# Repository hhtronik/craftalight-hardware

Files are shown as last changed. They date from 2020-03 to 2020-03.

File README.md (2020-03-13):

# Craftalight / Hardware
Schematics, BOM and mechanical drawings for Craftalight.

If you're looking for the firmware, it's over there: [craftalight-firmware in Github](https://github.com/hhtronik/craftalight-firmware/)

Fully assembled Craftalights are available on [hhtronik.com](https://hhtronik.com/product/craftalight-the-oshw-handbag-led-light/)

## What's in here?

You'll find a BOM with comments/notes, a PDF schematic, ECAD design files for DesignSpark and DXF drawings for the mechanical parts of Craftalight.

## Software

You open and edit most files by using free or open-source software.

- ECAD: DesignSpark PCB v9 by RS Online
- Mechanical: FreeCad or Fusion360

## LICENCE 

This part of the Craftalight project is licenced under **CERN Open Hardware Licence Version 2 - Strongly Reciprocal** see [LICENCE](./LICENCE) file

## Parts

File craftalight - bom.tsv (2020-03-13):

Reference | Component | Package | Value | Notes
SW1 | ALPS SKSNLAE010 |  |  | Tactile switch side mid mount (alternatively Panasonic EVPAEDB2A
C1 | MLCC 0805 10uF X7R | 0805 | 10uF 16V
C2 | MLCC 0402 1uF X7R | 0402 | 1uF 6.3V
C3 | MLCC 0402 1uF X7R | 0402 | 1uF 6.3V
C4 | MLCC 0402 100nF X7R | 0402 | 100nF 25V | Optional for alternative LDO with HF bypass
C6 | MLCC 0805 10uF X7R | 0805 | 10uF 16V
C7 | MLCC 0402 100nF X7R | 0402 | 100nF 25V
C8 | MLCC 0402 1uF X7R | 0402 | 1uF 6.3V
C9 | MLCC 0402 100nF X7R | 0402 | 100nF 25V
C11 | MLCC 0402 1uF X7R | 0402 | 1uF 6.3V
C12 | MLCC 0402 100nF X7R | 0402 | 100nF 25V
Q1 | Diodes Inc. DMG1012UW-7 | SOT-323 | 1A 20V N-mos
Q2 | Diodes Inc. DMG1012UW-7 | SOT-323 | 1A 20V N-mos
LED1 | 5630 Warm white (3200K) LED | 5630 | Vf=2.5V Imax=150mA CRI=85 | ex. OSRAM DURISE5. 5730 package fits footprint
LED2 | 5630 Warm white (3200K) LED | 5630 | Vf=2.5V Imax=150mA CRI=85 | ex. OSRAM DURISE5. 5730 package fits footprint
FS1 | Bourns MF-NSMF150 PTC fuse | 1206 | Umax=6V Ihold=1.5A
U1 | Microchip MIC5365-3.0YC5 LDO | SOT-323 | Uout=3.0V Imax=150mA
U2 | ST STM8S003F3U6TR | UFQFPN20 | 8bit STM8 Microcontroller, 16MHz, 8 kB Flash
U3 | Silicon Labs Si7201-B-05-IV Hall effect switch | SOT23-3 |  | Alternatively GoChip Elec Tech GH1248ESW (higher sensitivity and no tamper detection mode)
J1 | Mid-mount micro USB socket |  |  | XKB Enterprise U253-051T-4BH87
R1 | Resistor 18R 1% 0603 | 0603 | 18 Ohms and >= 1/4W dissipation | ex. Panasonic ERJPA3F18R0V
R2 | Resistor 10K 5% 0402 | 0402
R3 | Resistor 18R 1% 0603 | 0603 | 18 Ohms and >= 1/4W dissipation | ex. Panasonic ERJPA3F18R0V
R4 | Resistor 50R 1% 0603 | 0603 |  | ex. Bourns CR0603-FX-49R9ELF
R5 | Resistor 1M 1% 0402 | 0402
R6 | Resistor 1M 1% 0402 | 0402
R7 | Resistor 1M 1% 0402 | 0402
SO1 | Würth WA-SMSI 9774015243R 1.5mm Steel standoff M2
SO2 Würth WA-SMSI 9774015243R 1.5mm Steel standoff M2
MS1 Bossard BN1435 M2x6mm Phillips screw
MS2 Bossard BN1435 M2x6mm Phillips screw
G1 | EPDM gasket |  |  | 2mm EPDM sheet
CO1 | Acrylic glass, satin |  |  | Material: Plexiglas(r) Satinice(r) 3mm

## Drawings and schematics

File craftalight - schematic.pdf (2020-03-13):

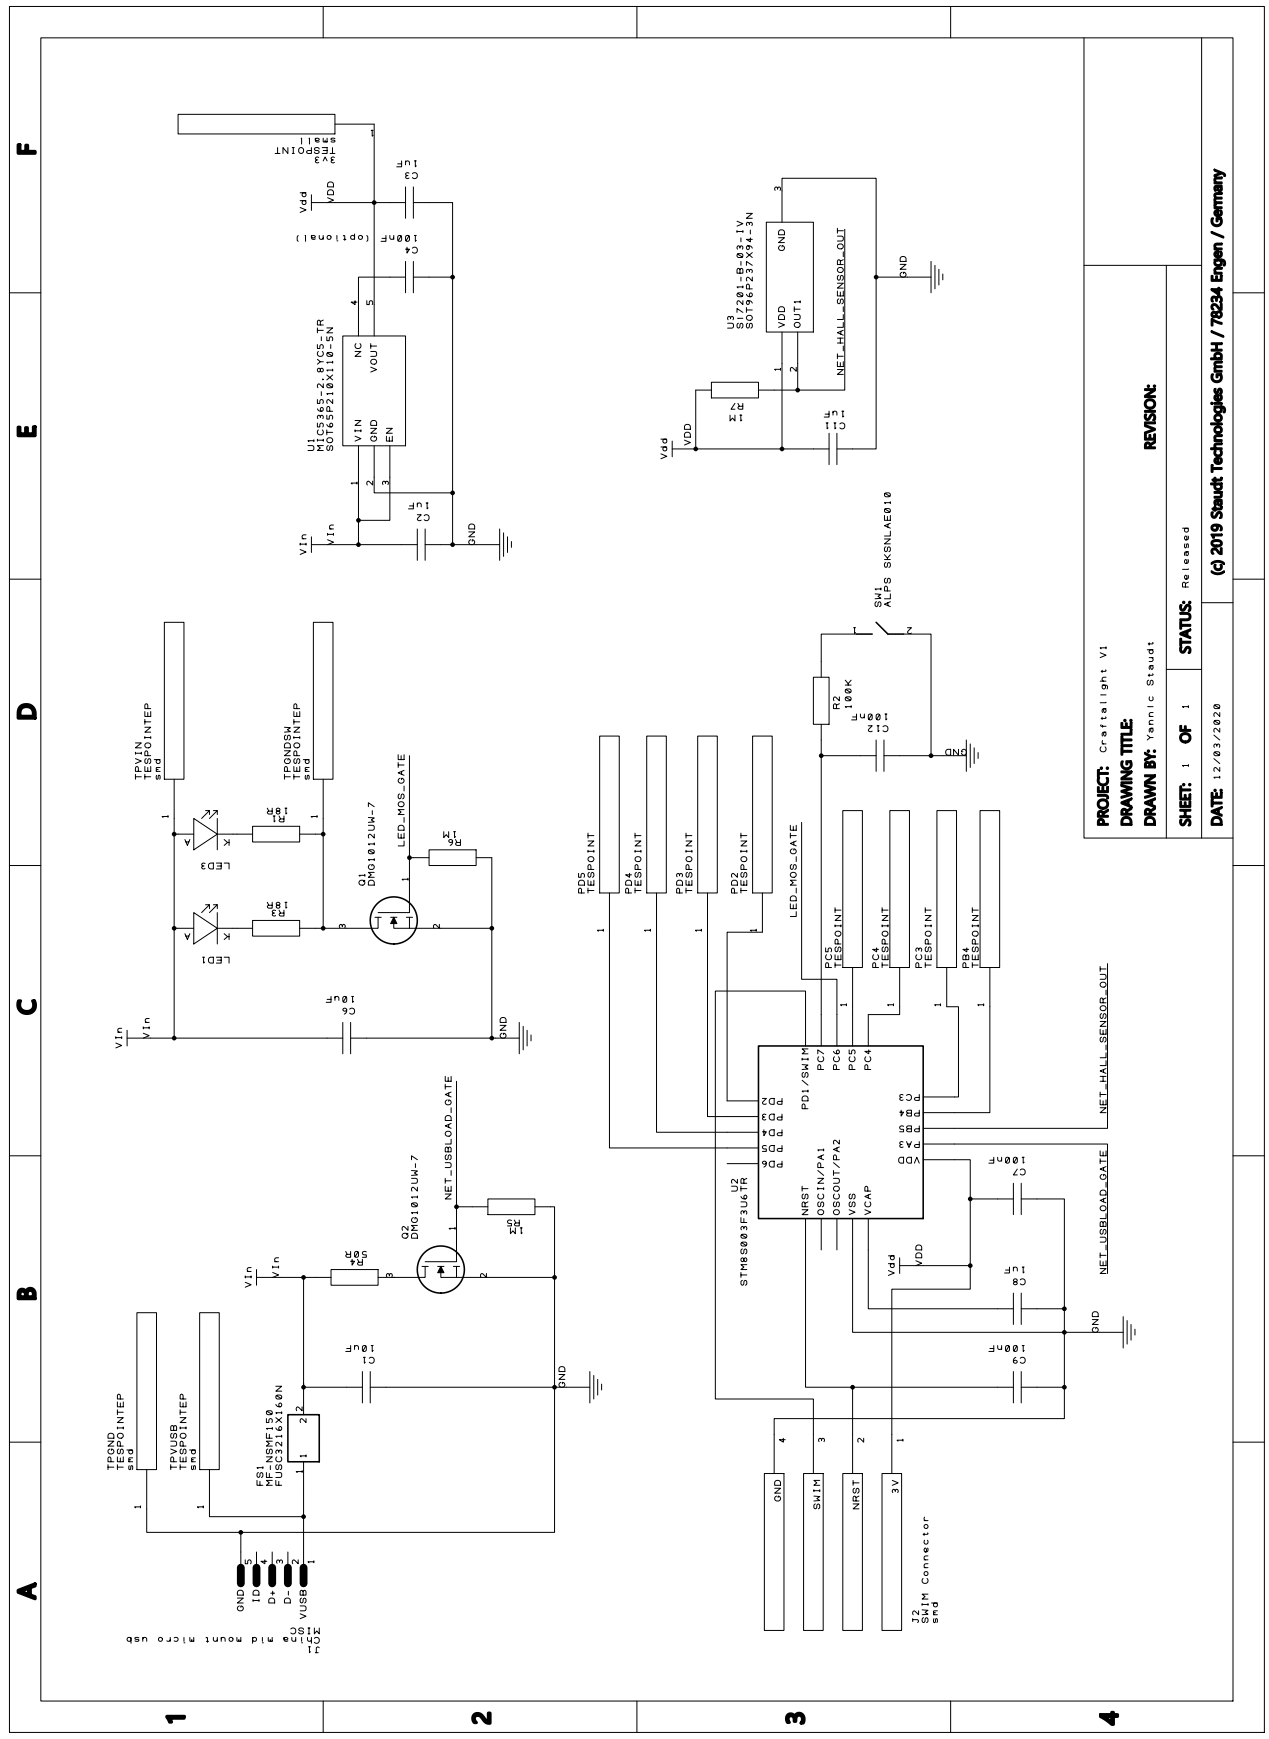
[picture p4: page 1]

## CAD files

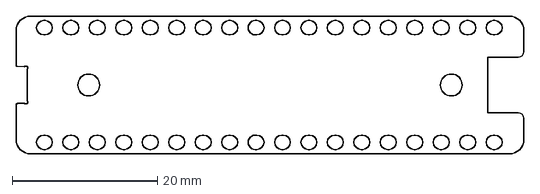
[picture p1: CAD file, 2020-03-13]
mechanical/pcb outline.dxf
70.0 x 19.0 mm

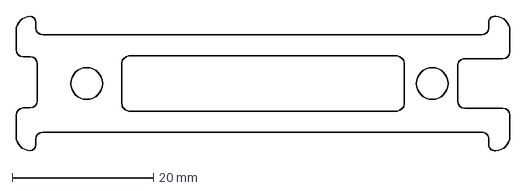
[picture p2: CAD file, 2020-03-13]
mechanical/epdm gasket.dxf
70.0 x 19.0 mm

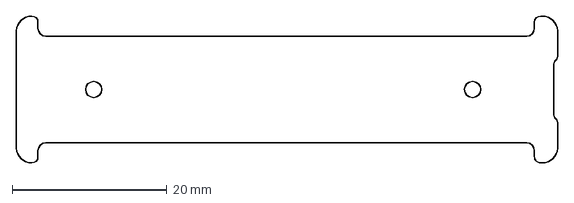
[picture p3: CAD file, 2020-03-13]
mechanical/acrylic cover.dxf
70.0 x 19.0 mm
